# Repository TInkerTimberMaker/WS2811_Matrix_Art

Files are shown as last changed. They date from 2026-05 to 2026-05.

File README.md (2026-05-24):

# Animated Hex Display + 8×12 Pixel Matrix

A desktop "blinkenlights" art piece built around an Arduino Nano. Eight
7-segment digits cycle through random hexadecimal characters with occasional
easter-egg words (`DEADBEEF`, `REBOOT`, `HALTC0DE`, ...) that roll into place
and dissolve away. Behind them, a 96-pixel WS2811 LED matrix runs ten
selectable animation modes, all driven by four front-panel knobs.

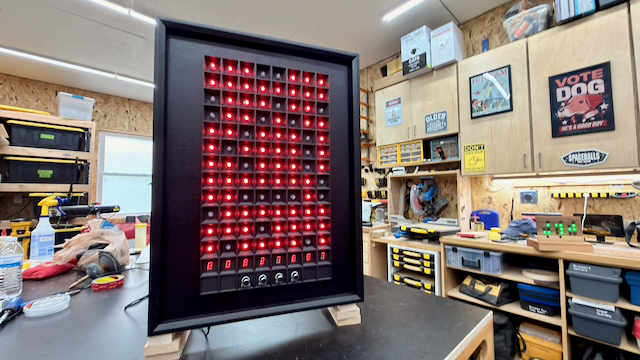
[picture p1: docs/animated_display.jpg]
hero shot


## Video
[Watch the video →](<https://youtu.be/your-video-id>)

## Features

- **8 seven-segment digits** driven by a single MAX7219 multiplexer
- **96 RGB pixels** (8 wide × 12 tall) on a single data pin, serpentine wiring
- **10 animation modes** selectable from a knob — see [Pixel modes](#pixel-modes)
- **Easter-egg words** roll into the 7-seg display occasionally, hold for a few
  seconds, then dissolve back to random hex
- **Four live controls** (program, hue, rate, brightness) — no menu diving
- **Encoder-style program selection** from a regular pot, using band detection +
  hysteresis + settle time
- **Single brightness knob** dims both displays together; fully off enters
  MAX7219 low-power shutdown
- All effects run at ~33 FPS on a stock Arduino Nano with room to spare
  (~42% flash, ~30% SRAM used)

## Hardware

| Qty | Part |
|-----|---|
| 1 | Arduino Nano (ATmega328P) |
| 1 | MAX7219 in a 28-pin DIP socket |
| 8 | 7-segment LEDs, common cathode |
| 1 | String of 100 WS2811 RGB pixels, 12 V |
| 4 | 10 kΩ linear potentiometers (program, hue, rate, brightness) |
| 1 | 12 V, 8 A power supply with barrel connector |
| 1 | Iset resistor for MAX7219 (sets segment current; ~10 kΩ for typical brightness) |
| 1 | ~330 Ω series resistor on the WS2811 data line |
| 2 | Perfboard ("greenboard"): 5×7 cm (main) + 3×5 cm (digit landing pad) |
| — | Hookup wire, headers, knob caps, etc. |

## 3D Printed Parts

STL files are in [`stl/`](stl/). They form the front panel and digit/pixel housings:

| File | Purpose |
|---|---|
| `stl/4x4_matrix_holder-12mm_bullet_pixels.stl` | 4x4 Frame that holds and aligns pixels. 6 needed for 8x12 matrix  |
| `stl/7-segment-led_holder.stl` | Bezel for the 8 seven-segment digits  |
| `stl/control_knobs.stl` | Front panel with mounting holes for the 4 pots |

**Print settings I used:** 0.2 mm layer height, 3 walls, 15% infill, PETG.
None of the parts need supports.

## Wiring
Arduino Nano MAX7219 / pixels / pots

- D6 ────────────► WS2811 DATA (through ~330 Ω series resistor)
- D11 ────────────► MAX7219 CS (LOAD)
- D12 ────────────► MAX7219 DIN
- D13 ────────────► MAX7219 CLK
- A0 ◄────────── Brightness pot wiper
- A1 ◄────────── Rate (speed) pot wiper
- A2 ◄────────── Hue pot wiper
- A3 ◄────────── Program pot wiper
- 5V ────────────► All pot top ends + MAX7219 V+
- GND ────────────► Common ground for everything

The MAX7219 drives the 8 digits with 16 lines (8 segments + 8 digit-enables)
using time-domain multiplexing — only one digit is lit at any instant, but the
refresh is fast enough that your eye sees all eight as continuously on. One
external resistor on `ISET` sets the per-segment current limit.

The 12 V supply powers the WS2811 string directly. The Arduino Nano can be
fed from the same supply via Vin (it has an onboard regulator) or powered
separately from USB during development. **Ground must be common between the
Nano, the pixel string, and the MAX7219.**

> ⚠️ **Logic level on the WS2811 data line:** Some 12 V WS2811 strips work fine
> with the Nano's 5 V data output, but if you see flicker or wrong colors,
> add a 74AHCT125 buffer or level shifter on the data pin.

## Software

### Install

1. Install the [Arduino IDE](https://www.arduino.cc/en/software).
2. Install the **Adafruit NeoPixel** library via Library Manager.
3. Open `Animated_Matrix_Display.ino` from this repo.
4. Select **Tools → Board → Arduino Nano** (and the correct processor variant
   if asked — usually ATmega328P, "Old Bootloader" for the cheap clones).
5. Upload.

### Pixel modes

| # | Mode | What it does |
|---|---|---|
| 0 | Solid + twinkles | Solid color with sparse white sparkles |
| 1 | Sweep ↑ | Brightness wave traveling bottom-to-top in a single color |
| 2 | Sweep → | Same but moving left-to-right |
| 3 | Retro data lights  | 1950s mainframe "blinkenlights" with occasional partial-row bursts |
| 4 | Data Page | Latches a random 96-bit page, holds, blanks, then re-latches |
| 5 | Matrix rain | Falling drops with fading trails |
| 6 | Scrolling waveform | Smooth random-walk samples flowing right-to-left |
| 7 | Diagonal scroll | Rainbow stripes scrolling diagonally |
| 8 | Snake walker | A bright head walks the grid with a fading tail |
| 9 | Plasma | Smooth flowing color field |

### How the knobs interact

- **Program** snaps to one of 10 discrete positions with hysteresis — turn it,
  pause briefly, and the new mode latches in. The 7-seg briefly shows
  `PROG-#`.
- **Hue** is continuous 0-255 in modes that take a single color.
- **Rate** is continuous 0-255 and each mode interprets it for its own pace.
- **Brightness** dims both displays together; fully counterclockwise puts the
  MAX7219 into shutdown.

### Customizing

Most of the per-mode tuning knobs are commented in the source. The big ones:

- **Add or remove easter-egg words** — edit the `WORDS[]` table near the top
  of the sketch. Each word is 8 characters of 7-seg-renderable text.
- **Easter-egg frequency** — `EGG_PERMILLE` (chance per check) and
  `EGG_CHECK_MS` (poll interval).
- **Matrix orientation** — flip `MATRIX_ORIGIN_RIGHT` and `MATRIX_SERPENTINE`
  to match how you wired your strip.
- **Color order** — if reds and greens look swapped, change `NEO_RGB` to
  `NEO_GRB` on the `Adafruit_NeoPixel` constructor.

## Dependencies

- [Adafruit NeoPixel](https://github.com/adafruit/Adafruit_NeoPixel)

## License

MIT — do whatever, attribution appreciated. 

## Acknowledgments

- Build sequence and animation tuning iterated with the help of an AI coding
  assistant — the project served as a great test of how far you can push
  an Arduino Nano with a chatty co-pilot.
- The seven-segment "scramble-into-word" reveal is loosely inspired by every
  hacker movie ever made.

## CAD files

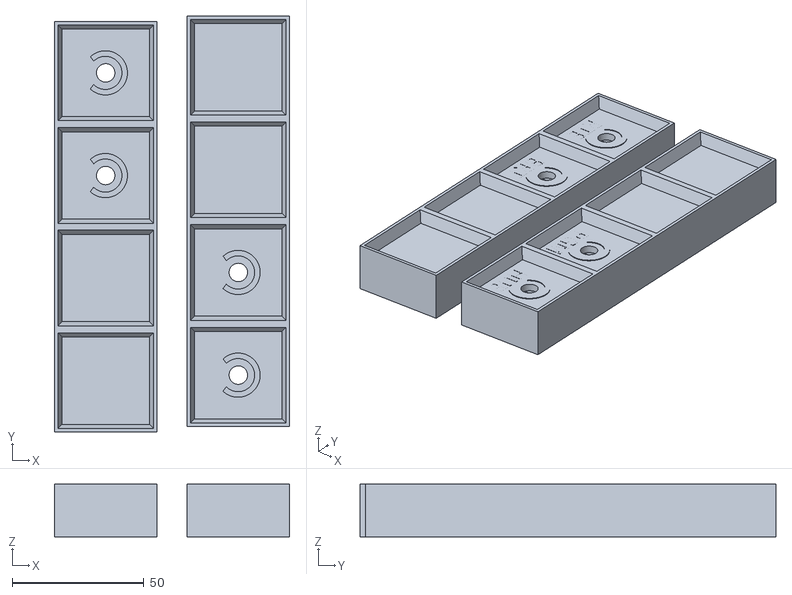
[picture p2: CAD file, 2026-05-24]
stl/control_knobs.stl
89.4 x 158.0 x 20.0

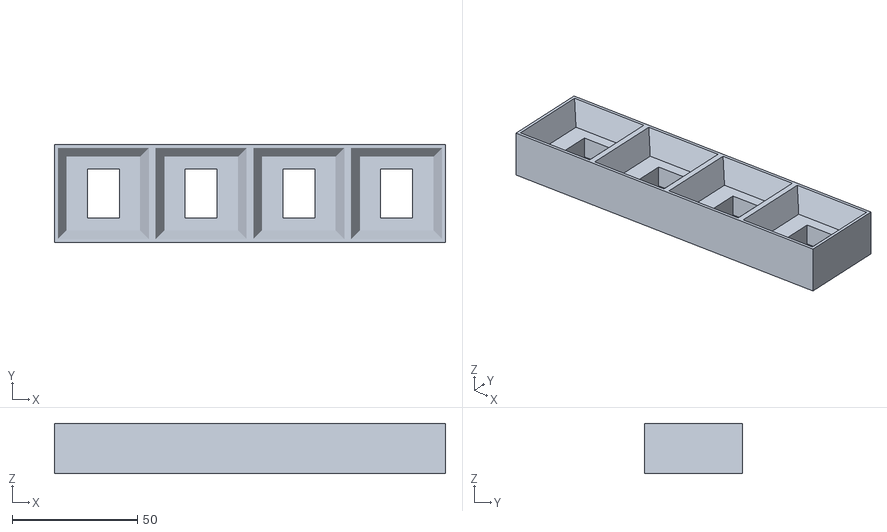
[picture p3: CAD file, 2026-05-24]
stl/7-segment-led_holder.stl
156.0 x 39.0 x 20.0

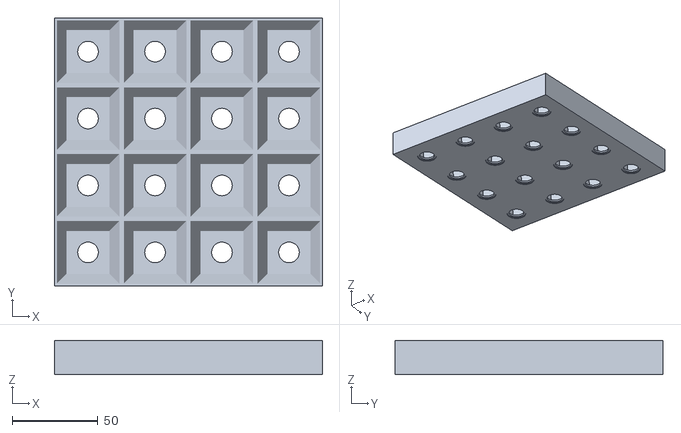
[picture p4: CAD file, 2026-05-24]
stl/4x4_matrix_holder-12mm_bullet_pixels.stl
156.0 x 155.8 x 20.0

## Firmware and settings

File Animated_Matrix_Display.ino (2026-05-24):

/* ============================================================================
 *  Animated Hex Display + 8x12 Pixel Matrix
 *  ----------------------------------------------------------------------------
 *  An Arduino Nano "blinkenlights" art piece combining:
 *    - 8x seven-segment digits (MAX7219) cycling through random hex characters
 *      with occasional "easter egg" words (DEADBEEF, REBOOT, etc.) that roll
 *      into place, hold for a few seconds, then dissolve back to random hex.
 *    - 96 pixel WS2811 LED matrix (8 wide x 12 tall, serpentine wiring) running
 *      ten selectable animation modes.
 *
 *  Four front-panel potentiometers act as live controls:
 *    A0  Brightness   -- dims 7-segs and matrix together; fully off enters
 *                        MAX7219 low-power shutdown.
 *    A1  Speed        -- animation rate; each mode interprets this differently.
 *    A2  Color        -- 0..255 hue for matrix modes that take a single color.
 *    A3  Program      -- 0..9 latched selection. The pot is treated like a
 *                        discrete 10-position rotary encoder via band
 *                        detection + hysteresis + settle time.
 *
 *  Wiring
 *    MAX7219:   DIN = D12,  CLK = D13,  CS = D11
 *    Pixels:    DATA = D6  (use a level shifter / 74AHCT125 for 12V WS2811)
 *    Pots:      All four on A0..A3 as listed above
 *
 *  Pixel modes
 *    0  Solid color + sparse twinkle overlay
 *    1  Solid color sweep, bottom -> top (brightness wave)
 *    2  Solid color sweep, left -> right (brightness wave)
 *    3  Retro mainframe "blinkenlights": discrete random blinks with bursts
 *    4  Data Page: latch a random 96-bit page, hold, blank, repeat
 *    5  Matrix rain (Cascade of single-color drops with fading trails)
 *    6  Scrolling waveform (right-to-left smooth random-walk samples)
 *    7  Diagonal rainbow scroll
 *    8  Snake walker with fading tail and random direction changes
 *    9  Plasma (sin-approximation color field)
 *
 *  Dependencies
 *    - Adafruit_NeoPixel library  (install via Arduino Library Manager)
 *
 * Copyright 2026 - Tinker & Timber
 *
 * ============================================================================ */

#include <avr/pgmspace.h>
#include <string.h>


// ============================================================================
//  Build-time configuration
// ============================================================================

#define DEBUG          1            // 1 = serial debug, 0 = silent release build
#define DEBUG_BAUD     115200

#define USE_NEOPIXEL   1            // 0 = disable all WS2811 code

// Debug macros: compile down to nothing when DEBUG = 0
#if DEBUG
  #define DBG_BEGIN()    Serial.begin(DEBUG_BAUD)
  #define DBG(x)         Serial.print(x)
  #define DBGLN(x)       Serial.println(x)
  #define DBG_F(x)       Serial.print(F(x))
  #define DBGLN_F(x)     Serial.println(F(x))
#else
  #define DBG_BEGIN()
  #define DBG(x)
  #define DBGLN(x)
  #define DBG_F(x)
  #define DBGLN_F(x)
#endif


// ============================================================================
//  Pixel matrix (WS2811) configuration
// ============================================================================
#if USE_NEOPIXEL
  #include <Adafruit_NeoPixel.h>

  #define LED_PIN              6
  #define MATRIX_W             8
  #define MATRIX_H             12
  #define NUM_LED              (MATRIX_W * MATRIX_H)

  #define MATRIX_ORIGIN_RIGHT  0    // 0: chain starts lower-LEFT,  1: lower-RIGHT
  #define MATRIX_SERPENTINE    1    // 0: all rows wired left-to-right
                                    // 1: zig-zag (every other row reversed)

  // NEO_RGB + 800kHz is correct for most 12V WS2811 strips.
  // If reds and greens look swapped, try NEO_GRB.
  // If the strip lights up solid white on every update, swap to NEO_KHZ400.
  Adafruit_NeoPixel strip(NUM_LED, LED_PIN, NEO_RGB + NEO_KHZ800);
#endif


// ============================================================================
//  MAX7219 wiring and segment mapping
// ============================================================================

#define DIN        12
#define CLK        13
#define CS         11
#define N_DIGITS   8

// Raw MAX7219 hardware segment bits. Adjust if your display's pinout differs.
#define SEG_DP     0x80
#define SEG_A      0x40
#define SEG_B      0x20
#define SEG_C      0x10
#define SEG_D      0x08
#define SEG_E      0x04
#define SEG_F      0x02
#define SEG_G      0x01

// Logical (wiring-agnostic) segment bits. Used by the glyph table below;
// remapped to hardware bits via SEG_MAP_PGM at draw time.
#define L_A        0x01
#define L_B        0x02
#define L_C        0x04
#define L_D        0x08
#define L_E        0x10
#define L_F        0x20
#define L_G        0x40
#define L_DP       0x80

// Maps display position (0..7, left to right) -> MAX7219 digit register (1..8).
// Customize if your digits are wired in a different physical order.
const uint8_t ORDER_PGM[8] PROGMEM = { 1, 5, 7, 3, 4, 8, 6, 2 };

// Maps a logical segment (L_A..L_DP) to a hardware segment bit (SEG_A..SEG_DP).
// Tweak this if individual segments of your display light up incorrectly.
const uint8_t SEG_MAP_PGM[8] PROGMEM = {
  /* A  */ SEG_B,
  /* B  */ SEG_G,
  /* C  */ SEG_DP,
  /* D  */ SEG_E,
  /* E  */ SEG_C,
  /* F  */ SEG_F,
  /* G  */ SEG_A,
  /* DP */ SEG_D
};

// Hex glyphs 0..F expressed as logical segment masks.
const uint8_t HEXL_PGM[16] PROGMEM = {
  /* 0 */ L_A|L_B|L_C|L_D|L_E|L_F,
  /* 1 */ L_B|L_C,
  /* 2 */ L_A|L_B|L_D|L_E|L_G,
  /* 3 */ L_A|L_B|L_C|L_D|L_G,
  /* 4 */ L_F|L_G|L_B|L_C,
  /* 5 */ L_A|L_F|L_G|L_C|L_D,
  /* 6 */ L_A|L_F|L_E|L_D|L_C|L_G,
  /* 7 */ L_A|L_B|L_C,
  /* 8 */ L_A|L_B|L_C|L_D|L_E|L_F|L_G,
  /* 9 */ L_A|L_B|L_C|L_D|L_F|L_G,
  /* A */ L_A|L_B|L_C|L_E|L_F|L_G,
  /* B */ L_C|L_D|L_E|L_F|L_G,
  /* C */ L_A|L_F|L_E|L_D,
  /* D */ L_B|L_C|L_D|L_E|L_G,
  /* E */ L_A|L_F|L_E|L_D|L_G,
  /* F */ L_A|L_F|L_E|L_G
};


// ============================================================================
//  Timing constants
// ============================================================================

// 7-segment digit cycling
#define MIN_MS            100      // shortest hold time for a single hex digit
#define MAX_MS            2500     // longest hold time for a single hex digit

// Easter-egg word reveal behaviour
#define EGG_ENABLED       1        // 0 = never show easter-egg words
#define EGG_HOLD_MS       8000     // how long the word stays on screen
#define EGG_CHECK_MS      10000    // poll interval for "should we trigger?"
#define EGG_COOLDOWN_MS   30000    // minimum gap between two egg appearances
#define EGG_PERMILLE      159      // chance per check, 0..1000 (159 = ~16%)


// ============================================================================
//  Program selector (A3 -> 0..9 latched mode)
// ============================================================================
// The program pot is binned into N_PROGRAMS equal-sized bands across the ADC
// range. To prevent flicker between adjacent bands, the pot value must remain
// inside the "core" of a band (shrunk by PROG_HYST_PCT on each side) for at
// least PROG_SETTLE_MS milliseconds before the new selection latches.

#define N_PROGRAMS            10
#define PROG_SETTLE_MS        120
#define PROG_HYST_PCT         15
#define ADC_FULL              1024
#define PROG_BAND             (ADC_FULL / N_PROGRAMS)
#define PROG_HYST             ((PROG_BAND * PROG_HYST_PCT + 50) / 100)

#define SHOW_PROGRAM_ON_MAX   1        // briefly show "PROG-#" on 7-seg on change
#define PROG_SHOW_MS          1000     // duration of that "PROG-#" overlay


// ============================================================================
//  Potentiometer pins and presence flags
// ============================================================================

#define POT_BRIGHT   A0
#define POT_SPEED    A1
#define POT_COLOR    A2
#define POT_MODE     A3

// Toggle to 0 if you haven't wired a pot on that input; the code will use the
// DEFAULT_* value instead and keep the pin pulled up (quiet) at runtime.
#define POT_BRIGHT_HAS  1
#define POT_COLOR_HAS   1
#define POT_SPEED_HAS   1
#define POT_MODE_HAS    1

// Fallback values when a pot is marked as not present.
#define DEFAULT_BRIGHT    5
#define DEFAULT_COLOR     128
#define DEFAULT_SPEED     128
#define DEFAULT_PROGRAM   0


// ============================================================================
//  Easter-egg word list (PROGMEM, 8 chars each)
// ============================================================================
#define WDEF(n,txt) const char n[] PROGMEM = txt;
WDEF(W00,"DEADBEEF")  WDEF(W01,"DEADC0DE")  WDEF(W02,"C0DEBASE")
WDEF(W03,"B00TL0AD")  WDEF(W04,"DEBUGGER")  WDEF(W05,"L0ADBYTE")
WDEF(W06,"C0REDR0P")  WDEF(W07,"C0FFEE")    WDEF(W08,"CACHED")
WDEF(W09,".0UTPUT.")  WDEF(W10,"1NPUT")     WDEF(W11,"5LA5HD0T")
WDEF(W12,"CLEARED")   WDEF(W13,"..5T0P..")  WDEF(W14,"5TART")
WDEF(W15,"--NERD--")  WDEF(W16,"--HALT--")  WDEF(W17,"C0NNECT")
WDEF(W18,"L0ADER")    WDEF(W19,"..L0AD..")  WDEF(W20,"..BU5Y..")
WDEF(W21,"HALTC0DE")  WDEF(W22,"READBYTE")  WDEF(W23,"..B00T..")
WDEF(W24,"NULLBYTE")  WDEF(W25,"L0AD.8.1")  WDEF(W26,"PUT.BYTE")
WDEF(W27,"IF..THEN")  WDEF(W28,"ENDIF")     WDEF(W29,"ELSEIF")
WDEF(W30,"D0.UNTIL")  WDEF(W31,"DIGITAL")   WDEF(W32,"ANALOG")
WDEF(W33,"JSR..RTS")  WDEF(W34,".REB00T.")  WDEF(W35,"LDA..STA")
WDEF(W36,"ERR0R.42")  WDEF(W37,"ERR0R")     WDEF(W38,"L0ADC0DE")
WDEF(W39,"UPDATING")  WDEF(W40,".UPDATE.")  WDEF(W41,"GET.BYTE")
WDEF(W42,"5318008")   WDEF(W43,".HALTED.")  

#undef WDEF

const char* const WORDS[] PROGMEM = {
  W00,W01,W02,W03,W04,W05,W06,W07,W08,W09,W10,W11,W12,W13,W14,W15,W16,W17,W18,W19,
  W20,W21,W22,W23,W24,W25,W26,W27,W28,W29,W30,W31,W32,W33,W34,W35,W36,W37,W38,W39,
  W40,W41,W42,W43
};
#define N_WORDS (sizeof(WORDS) / sizeof(WORDS[0]))


// ============================================================================
//  Low-level helpers
// ============================================================================

// Forward decls (Arduino auto-prototypes are usually fine, but explicit beats
// implicit when a header function uses one defined further down).
static inline void putMask_ifChanged(uint8_t pos, uint8_t mask);

// Bit-bang one register/data pair to the MAX7219.
static inline void send(uint8_t reg, uint8_t data) {
  digitalWrite(CS, LOW);
  shiftOut(DIN, CLK, MSBFIRST, reg);
  shiftOut(DIN, CLK, MSBFIRST, data);
  digitalWrite(CS, HIGH);
}

static inline uint8_t  rd8_P(const uint8_t* p)   { return pgm_read_byte(p); }
static inline uint8_t  orderReg(uint8_t pos)     { return rd8_P(&ORDER_PGM[pos]); }

// Time helpers in 16-bit and 32-bit flavors. The 16-bit forms wrap every
// ~65 seconds, which is fine for short-duration timers in the 7-seg loop and
// keeps the math cheap on AVR.
static inline uint16_t now16()                   { return (uint16_t)millis(); }
static inline bool     due(uint16_t t)           { return (int16_t)(now16() - t) >= 0; }
static inline uint32_t now32()                   { return millis(); }
static inline bool     due32(uint32_t t)         { return (int32_t)(now32() - t) >= 0; }

static inline void setIntensity(uint8_t lvl) {
  if (lvl > 15) lvl = 15;
  send(0x0A, lvl);
}

// Read an ADC pin with a throw-away read first to allow the MUX to settle.
static inline uint16_t adcReadStable(uint8_t pin) {
  analogRead(pin);
  delayMicroseconds(8);
  return analogRead(pin);
}

// Median of three stable reads -- cheap de-noise for jittery pots.
static uint16_t readStableADC3(uint8_t pin) {
  uint16_t a = adcReadStable(pin), b = adcReadStable(pin), c = adcReadStable(pin);
  if ((a <= b && b <= c) || (c <= b && b <= a)) return b;
  return (a < c) ? c : a;
}

// Apply 4-bit brightness to the MAX7219, with true power-off at nibble == 0.
static bool gMaxIsOff = false;
static inline void max7_applyBrightnessNib(uint8_t nib) {
  if (nib == 0) {
    if (!gMaxIsOff) { send(0x0C, 0x00); gMaxIsOff = true; }   // shutdown
  } else {
    if (gMaxIsOff)  { send(0x0C, 0x01); gMaxIsOff = false; }  // wake
    setIntensity(nib);
  }
}

// Remap logical segment bits (L_A..L_DP) to MAX7219 hardware bits.
static inline uint8_t remap(uint8_t logical) {
  uint8_t m = 0;
  if (logical & L_A ) m |= rd8_P(&SEG_MAP_PGM[0]);
  if (logical & L_B ) m |= rd8_P(&SEG_MAP_PGM[1]);
  if (logical & L_C ) m |= rd8_P(&SEG_MAP_PGM[2]);
  if (logical & L_D ) m |= rd8_P(&SEG_MAP_PGM[3]);
  if (logical & L_E ) m |= rd8_P(&SEG_MAP_PGM[4]);
  if (logical & L_F ) m |= rd8_P(&SEG_MAP_PGM[5]);
  if (logical & L_G ) m |= rd8_P(&SEG_MAP_PGM[6]);
  if (logical & L_DP) m |= rd8_P(&SEG_MAP_PGM[7]);
  return m;
}

static inline void putHex(uint8_t pos, uint8_t n) {
  putMask_ifChanged(pos, remap(pgm_read_byte(&HEXL_PGM[n & 0xF])));
}

// Looks up the segment mask for a printable ASCII character. Unsupported
// characters return 0 (blank). The 7-seg can't render everything; this is the
// curated subset used by the easter-egg words above.
static uint8_t glyphFor(char ch) {
  switch (ch) {
    case '0': return L_A|L_B|L_C|L_D|L_E|L_F;
    case '1': return L_B|L_C;
    case '2': return L_A|L_B|L_D|L_E|L_G;
    case '3': return L_A|L_B|L_C|L_D|L_G;
    case '4': return L_F|L_G|L_B|L_C;
    case '5': case 'S': case 's': return L_A|L_F|L_G|L_C|L_D;
    case '6': return L_A|L_F|L_E|L_D|L_C|L_G;
    case '7': return L_A|L_B|L_C;
    case '8': return L_A|L_B|L_C|L_D|L_E|L_F|L_G;
    case '9': return L_A|L_B|L_C|L_D|L_F|L_G;
    case 'A': case 'a': return L_A|L_B|L_C|L_E|L_F|L_G;
    case 'B': case 'b': return L_C|L_D|L_E|L_F|L_G;
    case 'C': case 'c': return L_A|L_F|L_E|L_D;
    case 'D': case 'd': return L_B|L_C|L_D|L_E|L_G;
    case 'E': case 'e': return L_A|L_F|L_E|L_D|L_G;
    case 'F': case 'f': return L_A|L_F|L_E|L_G;
    case 'G': case 'g': return L_A|L_F|L_E|L_D|L_C;
    case 'H': case 'h': return L_B|L_C|L_E|L_F|L_G;
    case 'I': case 'i': return L_B|L_C;
    case 'J':           return L_B|L_C|L_D|L_E;
    case 'L':           return L_F|L_E|L_D;
    case 'N': case 'n': return L_C|L_E|L_G;
    case 'O': case 'o': return L_A|L_B|L_C|L_D|L_E|L_F;
    case 'P':           return L_A|L_B|L_E|L_F|L_G;
    case 'R': case 'r': return L_E|L_G;
    case 'T': case 't': return L_D|L_E|L_F|L_G;
    case 'U':           return L_B|L_C|L_D|L_E|L_F;
    case 'Y': case 'y': return L_B|L_C|L_D|L_F|L_G;
    case 'Z': case 'z': return L_A|L_B|L_D|L_E|L_G;
    case '-':           return L_G;
    case '.':           return L_DP;
    default:            return 0;
  }
}

// Read up to 8 characters from WORDS[idx] into buf[]; null-terminates.
static void readWord8(uint8_t idx, char buf[9]) {
  const char* p = (const char*)pgm_read_word(&WORDS[idx]);
  uint8_t n = 0;
  char c;
  while (n < 8 && (c = pgm_read_byte(p++))) buf[n++] = c;
  buf[n] = '\0';
}

// Pad a word out to 8 characters with '-' and pick a random horizontal offset.
static void buildDashed8_P(uint8_t idx, char out8[9]) {
  char tmp[9]; readWord8(idx, tmp);
  for (uint8_t i = 0; tmp[i]; ++i) if (tmp[i] == ' ') tmp[i] = '-';
  uint8_t len   = strlen(tmp); if (len > 8) len = 8;
  uint8_t room  = 8 - len;
  uint8_t start = room ? random(room + 1) : 0;
  for (uint8_t i = 0; i < 8; i++) out8[i] = '-';
  for (uint8_t i = 0; i < len; i++) out8[start + i] = tmp[i];
  out8[8] = '\0';
}


// ============================================================================
//  MAX7219 write-cache (skip redundant SPI traffic)
// ============================================================================
static uint8_t shadowMask[8];
static bool    shadowInit = false;

static inline void putMask_ifChanged(uint8_t pos, uint8_t mask) {
  if (!shadowInit) {
    for (uint8_t i = 0; i < 8; i++) shadowMask[i] = 0xFF;
    shadowInit = true;
  }
  if (shadowMask[pos] == mask) return;
  shadowMask[pos] = mask;
  send(orderReg(pos), mask);
}


// ============================================================================
//  Program selector (A3 pot acting like a discrete 10-position encoder)
// ============================================================================
struct ProgSel {
  uint8_t  latched;       // currently confirmed program (0..9)
  uint8_t  pending;       // candidate awaiting settle (255 = none)
  uint32_t pendUntil;     // millis() time when candidate would latch
} gProgSel = {0, 255, 0};

static uint32_t progShowUntil = 0;       // "PROG-#" overlay end time on 7-seg

// Returns the band index 0..N_PROGRAMS-1 that contains the given ADC value.
static inline uint8_t progBandOf(uint16_t adc) {
  uint16_t idx = (uint32_t)adc * N_PROGRAMS / ADC_FULL;
  if (idx >= N_PROGRAMS) idx = N_PROGRAMS - 1;
  return (uint8_t)idx;
}

static inline uint16_t bandStart(uint8_t idx) {
  return (uint16_t)((uint32_t)idx * ADC_FULL / N_PROGRAMS);
}
static inline uint16_t bandEnd(uint8_t idx) {
  return (uint16_t)(((uint32_t)(idx + 1) * ADC_FULL / N_PROGRAMS) - 1);
}

// True if the ADC value sits inside the band core (band shrunk by hysteresis).
static inline bool progInEnterWindow(uint16_t adc, uint8_t idx) {
  uint16_t s = bandStart(idx), e = bandEnd(idx);
  uint16_t width = e - s + 1;
  uint16_t h     = (uint16_t)((width * PROG_HYST_PCT + 50) / 100);
  uint16_t coreS = s + h;
  uint16_t coreE = (e > h) ? (e - h) : e;
  if (coreE < coreS) coreE = coreS;
  return (adc >= coreS && adc <= coreE);
}

// Shows "PROG-#" briefly on the 7-seg whenever the program latches to a new value.
static void max7_showProgram(uint8_t idx) {
  putMask_ifChanged(0, 0);
  putMask_ifChanged(1, remap(glyphFor('P')));
  putMask_ifChanged(2, remap(glyphFor('R')));
  putMask_ifChanged(3, remap(glyphFor('0')));
  putMask_ifChanged(4, remap(glyphFor('G')));
  putMask_ifChanged(5, remap(glyphFor('-')));
  putHex          (6, idx % 10);
  putMask_ifChanged(7, 0);
}

static void onProgramChanged(uint8_t idx) {
#if SHOW_PROGRAM_ON_MAX
  progShowUntil = millis() + PROG_SHOW_MS;
  max7_showProgram(idx);
#endif
}

// Core state machine: returns the currently latched program.
// Updates pending/latch state as the pot moves.
static uint8_t programSelector_updateADC(uint16_t adc) {
  uint8_t cand = progBandOf(adc);
  uint32_t now = millis();

  if (cand == gProgSel.latched) {
    gProgSel.pending   = 255;
    gProgSel.pendUntil = 0;
    return gProgSel.latched;
  }

  if (progInEnterWindow(adc, cand)) {
    if (gProgSel.pending != cand) {
      gProgSel.pending   = cand;
      gProgSel.pendUntil = now + PROG_SETTLE_MS;
    } else if ((int32_t)(now - gProgSel.pendUntil) >= 0) {
      gProgSel.latched   = cand;
      gProgSel.pending   = 255;
      gProgSel.pendUntil = 0;
      DBG_F("[prog] adc=");      DBG((int)adc);
      DBG_F(" latched=");        DBG((int)gProgSel.latched);
      DBG_F(" tms=");            DBGLN((unsigned)millis());
      onProgramChanged(gProgSel.latched);
    }
  } else {
    gProgSel.pending = 255;
  }
  return gProgSel.latched;
}


// ============================================================================
//  Pot reading + global control struct
// ============================================================================
struct Controls {
  uint8_t brightNib;     // A0, 0..15
  uint8_t color;         // A2, 0..255
  uint8_t speed;         // A1, 0..255
  uint8_t program;       // A3 raw (kept for any legacy use), 0..255
  uint8_t progIndex;     // A3 latched, 0..N_PROGRAMS-1
} gCtl;

// Cubic gamma curve (perceptual) for the WS2811 brightness, no floats:
// out = round(255 * (in / 15)^3)
static inline uint8_t gamma8_fromNib(uint8_t i) {
  uint16_t ii  = (uint16_t)i * i;
  uint32_t iii = (uint32_t)ii * i;
  return (uint8_t)((iii * 255UL + 1687UL) / 3375UL);
}

static void controls_begin() {
  #if POT_BRIGHT_HAS
    pinMode(POT_BRIGHT, INPUT);
  #else
    pinMode(POT_BRIGHT, INPUT_PULLUP);
  #endif
  #if POT_COLOR_HAS
    pinMode(POT_COLOR, INPUT);
  #else
    pinMode(POT_COLOR, INPUT_PULLUP);
  #endif
  #if POT_SPEED_HAS
    pinMode(POT_SPEED, INPUT);
  #else
    pinMode(POT_SPEED, INPUT_PULLUP);
  #endif
  #if POT_MODE_HAS
    pinMode(POT_MODE, INPUT);
  #else
    pinMode(POT_MODE, INPUT_PULLUP);
  #endif
}

static void controls_update() {
  #if POT_BRIGHT_HAS
    gCtl.brightNib = (uint8_t)(adcReadStable(POT_BRIGHT) >> 6);     // 0..15
  #else
    gCtl.brightNib = DEFAULT_BRIGHT;
  #endif

  #if POT_COLOR_HAS
    gCtl.color = (uint8_t)(adcReadStable(POT_COLOR) >> 2);          // 0..255
  #else
    gCtl.color = DEFAULT_COLOR;
  #endif

  #if POT_SPEED_HAS
    gCtl.speed = (uint8_t)(adcReadStable(POT_SPEED) >> 2);          // 0..255
  #else
    gCtl.speed = DEFAULT_SPEED;
  #endif

  #if POT_MODE_HAS
    uint16_t rawProg = readStableADC3(POT_MODE);                     // 0..1023
    gCtl.program   = (uint8_t)(rawProg >> 2);                        // 0..255 legacy
    gCtl.progIndex = programSelector_updateADC(rawProg);             // 0..9 stable
  #else
    gCtl.program   = DEFAULT_PROGRAM;
    gCtl.progIndex = DEFAULT_PROGRAM % N_PROGRAMS;
  #endif

  // Drive both displays from the same brightness pot.
  max7_applyBrightnessNib(gCtl.brightNib);

  #if USE_NEOPIXEL
    strip.setBrightness(gamma8_fromNib(gCtl.brightNib));
  #endif
}


// ============================================================================
//  7-segment animation: random hex + occasional easter-egg word reveal
// ============================================================================
enum Mode { MODE_NORMAL, MODE_ROLLIN, MODE_HOLD, MODE_ROLLOUT };
static Mode mode = MODE_NORMAL;

// Per-digit timing and current value
static uint8_t   curNib[8];                  // current displayed nibble (0..15)
static uint16_t  nextAt16[8];                // when this digit will reshuffle
static uint16_t  nextScr16[8];               // scramble tick during ROLLIN
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
void loop()  { max7_update(); }

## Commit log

2026-05-24 Animated art to run on an Arduino
2026-05-24 STL files for project
    [4x4_matrix_holder-12mm_bullet_pixels.stl, 7-segment-led_holder.stl, control_knobs.stl]
